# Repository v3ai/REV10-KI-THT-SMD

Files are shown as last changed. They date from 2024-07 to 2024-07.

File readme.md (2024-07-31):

These are the Kicad files for the REV-10 NSE Geiger Counter

make sure the R7 and R8 Resistors are 1% not 5%

if you wanna manufacture with jlcpcb use the included zip file. If you change anything please refer to the article below

https://jlcpcb.com/help/article/362-how-to-generate-gerber-and-drill-files-in-kicad-7

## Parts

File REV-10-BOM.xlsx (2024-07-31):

QTY | VALUE | PARTS | DESCRIPTION | MANUFACTURER PART NUMBER | VENDOR PART NUMBER | UNIT PRICE (IN 100+ BRACKET) | EXT PRICE | MEASUREMENT | SOURCE
 |  |  | RESISTORS (THT)
1 | 5.1kΩ | R1 | 1/2W resistor, metal film 700V | MF1/2CC5101F | S5.1KCACT-ND | 0.3011 | 0.3011 | 0.138" Dia x 0.354" L (3.50mm x 9.00mm) | https://www.digikey.com/en/products/detail/koa-speer-electronics-inc/MF1-2CC5101F/21680989
3 | 10kΩ | R2, R6, R9 | 1/4W resistor, carbon film | CF14JT10K0 | CF14JT10K0CT-ND | 0.0215 | 0.0645 | 0.091" Dia x 0.236" L (2.30mm x 6.00mm) | https://www.digikey.com/en/products/detail/CF14JT10K0/CF14JT10K0CT-ND/1830374
1 | 1kΩ | R3 | 1/4W resistor, carbon film | CF14JT1K00 | CF14JT1K00CT-ND | 0.0215 | 0.0215 | 0.091" Dia x 0.236" L (2.30mm x 6.00mm) | https://www.digikey.com/en/products/detail/CF14JT1K00/CF14JT1K00CT-ND/1830350
1 | 75Ω | R4 | 1/4W resistor, carbon film | CF14JT75R0 | CF14JT75R0CT-ND | 0.0215 | 0.0215 | 0.091" Dia x 0.236" L (2.30mm x 6.00mm) | https://www.digikey.com/en/products/detail/CF14JT75R0/CF14JT75R0CT-ND/1830324
1 | 6.2kΩ | R5 | 1/4W resistor, carbon film | CF14JT6K20 | CF14JT6K20CT-ND | 0.0215 | 0.0215 | 0.091" Dia x 0.236" L (2.30mm x 6.00mm) | https://www.digikey.com/en/products/detail/CF14JT6K20/CF14JT6K20CT-ND/1830369
1 | 4.7MΩ | R7 | 1/4W resistor, metal film, 1% (not 5%) | RNV14FAL4M70 | RNV14FAL4M70CT-ND | 0.063 | 0.063 | 0.094" Dia x 0.236" L (2.40mm x 6.00mm) | https://www.digikey.com/en/products/detail/stackpole-electronics-inc/RNV14FAL4M70/2665263
1 | 6.8MΩ | R8 | 0.6W resistor, carbon film, 1% (not 5%) | MBB02070C6804FCT00 | BC3869CT-ND | 0.076 | 0.076 | 0.091" Dia x 0.236" L (2.30mm x 6.00mm) | https://www.digikey.com/en/products/detail/vishay-beyschlag-draloric-bc-components/MBB02070C6804FCT00/5063554
2 | 4.7kΩ | R10, R14 | 1/4W resistor, carbon film | CF14JT4K70 | CF14JT4K70CT-ND | 0.0215 | 0.043 | 0.091" Dia x 0.236" L (2.30mm x 6.00mm) | https://www.digikey.com/en/products/detail/stackpole-electronics-inc/CF14JT4K70/1741428
1 | 10MΩ | R11 | 1/4W resistor, metal film 700V | VR25000001005JR500 | 56-VR25000001005JR500CT-ND | 0.1181 | 0.1181 | 0.098" Dia x 0.256" L (2.50mm x 6.50mm) | https://www.digikey.com/en/products/detail/vishay-beyschlag-draloric-bc-components/VR25000001005JR500/7350776
1 | 22kΩ | R12 | 1/4W resistor, carbon film | CF14JT22K0 | CF14JT22K0CT-ND | 0.0215 | 0.0215 | 0.091" Dia x 0.236" L (2.30mm x 6.00mm) | https://www.digikey.com/en/products/detail/CF14JT22K0/CF14JT22K0CT-ND/1830383
1 | 5.1MΩ | R13 | 1/4W resistor, metal film 700V | VR25000005104JA100 | BC4890CT-ND | 0.0978 | 0.0978 | 0.098" Dia x 0.256" L (2.50mm x 6.50mm) | https://www.digikey.com/en/products/detail/vishay-beyschlag-draloric-bc-components/VR25000005104JA100/7350796
1 | 20kΩ | RV1 | Potentiometer, 1/2W 1.0 Turn | 3362P-1-203LF | 3362P-203LF-ND | 0.7575 | 0.7575 | 0.275" x 0.260" Face (6.99mm x 6.60mm) | https://www.digikey.com/en/products/detail/bourns-inc/3362P-1-203LF/1088417
 |  |  | CAPACITORS (THT)
2 | 10uF | C1, C3 | MLCC in radial package with 0.1” lead spacing required | FG18X5R1E106MRT06 | 445-FG18X5R1E106MRT06CT-ND | 0.2043 | 0.4086 | 0.157" L x 0.098" W (4.00mm x 2.50mm) | https://www.digikey.com/en/products/detail/tdk-corporation/FG18X5R1E106MRT06/7384735
1 | 47pF | C2 | MLCC in radial package with 0.1” lead spacing required | SR152A470KAR | 478-3164-ND | 0.1315 | 0.1315 | 0.150" L x 0.100" W (3.81mm x 2.54mm) | https://www.digikey.com/en/products/detail/SR152A470KAR/478-3164-ND/936806
1 | 10nF = 10000pF | C4 | Ceramic in radial package 100V 0.2" lead spacing required | D103M29Z5UH6UJ5R | BC5213CT-ND | 0.062 | 0.062 | 0.295" Dia (7.50mm) | https://www.digikey.com/en/products/detail/vishay-beyschlag-draloric-bc-components/D103M29Z5UH6UJ5R/2830060
1 | 220n = 0.22uF | C5 | Ceramic in radial package with 0.2" lead spacing required | K224K20X7RF5UH5 | BC2678CT-ND | 0.124 | 0.124 | 0.197" L x 0.126" W (5.00mm x 3.20mm) | https://www.digikey.com/en/products/detail/vishay-beyschlag-draloric-bc-components/K224K20X7RF5UH5/2356767
1 | 1uF | C6 | Ceramic in radial package with 0.2” lead spacing required | FG28X7R1E105KRT00 | 445-181761-ND | 0.0899 | 0.0899 | 0.157" L x 0.098" W (4.00mm x 2.50mm) | https://www.digikey.com/en/products/detail/tdk-corporation/FG28X7R1E105KRT00/7326783
1 | 15nF | C7 | Ceramic in radial package with 0.15" lead spacing required | K153K10X7RF5UH5 | BC2671CT-ND | 0.0775 | 0.0775 | 0.142" L x 0.091" W (3.60mm x 2.30mm) | https://www.digikey.com/en/products/detail/vishay-beyschlag-draloric-bc-components/K153K10X7RF5UH5/2356760
1 | 4.7nF | C8 | Ceramic in radial package with 0.2” lead spacing required (CHV) | S472M39Z5UN63J5R | 1288PH-ND | 0.1444 | 0.1444 | 0.394" Dia (10.00mm) | https://www.digikey.com/en/products/detail/S472M39Z5UN63J5R/1288PH-ND/2356824
 |  |  | INDUCTORS
1 | 1mH | L1 | Inductor, radial package | RLB0914-102KL | RLB0914-102KL-ND | 0.26875 | 0.26875 | 0.343" Dia (8.70mm) | https://www.digikey.com/en/products/detail/bourns-inc/RLB0914-102KL/2352773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
 |  |  | DIODES
1 | LED | D1 | Blue LED 3mm,3 3.3V | WP710A10QBC/D | 754-1596-ND | 0.151 | 0.151 | 2.90mm Dia | https://www.digikey.com/en/products/detail/WP710A10QBC%2FD/754-1596-ND/2769812
1 | BA159 | D2 | Fast switching diode, DO-41 package required | BA159-E3/54 | BA159-E3/54GICT-ND | 0.1171 | 0.1171 | DO-204AL (DO-41) | https://www.digikey.com/en/products/detail/BA159-E3%2F54/BA159-E3%2F54GICT-ND/3711780
 |  |  | IC
1 | NJM78M05FA | U1 | Linear Voltage Regulator 5V at 500mA | NJM78M05FA | 2129-NJM78M05FA-ND | 0.7562 | 0.7562 | TO-220F | https://www.digikey.com/en/products/detail/nisshinbo-micro-devices-inc/NJM78M05FA/805792
1 | LMC555 | U2 | LMC555 CMOS-based 555 timer | LMC555CN/NOPB | LMC555CN/NOPB-ND | 1.10575 | 1.10575 | 8-DIP (0.300", 7.62mm) | https://www.digikey.com/en/products/detail/texas-instruments/LMC555CN-NOPB/32623
2 | STQ | U3, U4 | N Channel MOSFET 600V 400MA TO92-3 | STQ1HNK60R-AP | 497-15648-1-ND | 0.3879 | 0.7758 | TO-92-3 | https://www.digikey.com/en/products/detail/stmicroelectronics/STQ1HNK60R-AP/3945986
1 | TL5001 | U5 | Power converter control chip | TL5001AIP | 296-10203-5-ND | 2.9365 | 2.9365 | 8-DIP (0.300", 7.62mm) | https://www.digikey.com/en/products/detail/texas-instruments/TL5001AIP/380448
1 | 2N3904 | Q1 | NPN Transistor, TO-92 package | 2N3904BU | 2N3904FS-ND | 0.1169 | 0.1169 | TO-226-3, TO-92-3 (TO-226AA) | https://www.digikey.com/en/products/detail/2N3904BU/2N3904FS-ND/1413
 |  |  | MISC
1 | SBM-20 |  | Geiger Tube | SBM-20 | SBM-20 | 13 | 13 | Max Len = 108 / 101 Eff Length =91.0 / 83.5 (mm) | https://www.sovtube.com/x-ray-and-geiger-tubes/341-sbm-20.html
2 | DIP8 |  | DIP SOCKET 8 pos | ED08DT | ED3044-5-ND | 0.16283 | 0.32566 | DIP, 0.3" (7.62mm) Row Spacing | https://www.digikey.com/en/products/detail/ED08DT/ED3044-5-ND/4147594
2 | CLIPS |  | Fuse clips to hold SBM-20 | 3530 | 36-3530-ND | 0.2635 | 0.527 | Fuse Size 0.25" Dia (6.35mm) | https://www.digikey.com/en/products/detail/keystone-electronics/3530/316021
1 | BOARD |  | MIT-NSE Geiger Counter Board | REV9 | REV9 | 1.1677 | 1.1677 | <BOARD DIMENSIONS> | https://jlcpcb.com/
1 | CASE |  | Serpac enclosure, black, clear top | 052C,BK | 052C,BK | 7.29 | 7.29 | 5.62 x 3.25 x 1.4 in | https://www.serpac.com/x5x-enclosure.html#93=250&162=31&167=60&170=219&177=95&182=253
1 | SWITCH |  | SPST Circular Switch | SW-R2-1A-F-1-5 | 2057-SW-R2-1A-F-1-5-ND | 0.4232 | 0.4232 | Circular - 20.00mm Dia | https://www.digikey.com/en/products/detail/adam-tech/SW-R2-1A-F-1-5/15284451
1 | HOLD |  | 9V Battery holder | BA9VPC | BA9VPC-ND | 1.7901 | 1.7901 | Height Above Board 0.843" (21.41mm) | https://www.digikey.com/en/products/detail/mpd-memory-protection-devices/BA9VPC/2439228
1 | BATT |  | Energizer Industrial 9V | EN22 | EN22 | 1.431 | 1.431 | 49x46.5mm | https://a.co/d/gEASXDG
2 | SPADE |  | Spade Connectors | 197084013 | WM14275CT-ND | 0.0836 | 0.1672 | Length 0.510" (12.95mm), Width 0.187" (4.75mm) | https://www.digikey.com/en/products/detail/molex/0197084013/3183362
4 | SCREW |  | #4-40x3/16” pan head thread-cutting screw | 90087A105 | 90087A105 | 0.1018 | 0.4072 | #4-40x3/16” | https://www.mcmaster.com/90087A105/
2 | CONN |  | Female To Female spade connection wires (4.8mm) | N/A | N/A | 0.467 | 0.934 | 4.8mm spade, 11.82" Length | https://a.co/d/c38sBzh
1 | AUDIO | J2 | Audio Connection Jack (female) 3.5mm | 54-00298 | 839-54-00298CT-ND | 0.8888 | 0.8888 | 3.50mm (0.141", 1/8", Mini Plug) - Headphone | https://www.digikey.com/en/products/detail/tensility-international-corp/54-00298/16579528
 |  |  | OPTIONAL
1 | ESP32 |  | ESP32-C3-DevKitC-02 | ESP32-C3-DevKitC-02 | 356-ESP32C3DEVKITC02 | 8 | 8 |  | https://www.mouser.com/ProductDetail/Espressif-Systems/ESP32-C3-DevKitC-02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
2 | HEADER |  | 15 POS Female pinheader | PPTC151LFBN-RC | S7013-ND | 0.75075 | 1.5015 | Pitch - Mating 0.100" (2.54mm) | https://www.digikey.com/en/products/detail/sullins-connector-solutions/PPTC151LFBN-RC/810153
1 | PWR | J1 | 9V Connection Power Jack (Female) 2.1X5.5mm | EJ508A | EJ508A-ND | 1.0443 | 1.0443 | 2.1x5.5mm | https://www.digikey.com/en/products/detail/mpd-memory-protection-devices/EJ508A/2439547
1 | M4011 |  | Alternate usable geiger tube | M4011
 |  |  | PACKAGING
1 | BOX |  | 8 x 8 x 2-Inch Literature Mailers |  |  | 0.8014 | 0.8014 | 8" x 8" x 2" | https://a.co/d/04CDcmVn
7 | PINK BAG |  | Pink Anti-Static Seal Top Bag |  |  | 0.083 | 0.581 | 2.5" x 3" | https://a.co/d/08yDM0mG
27 | BAG |  | Zipper Lock Reclosable Clear Disposable Plastic Bags |  |  | 0.01299 | 0.35073 | 2" X 3" - 2 MIL | https://a.co/d/06HEltN5
1 | BUBBLE |  | Anti Static Bubble coushining for SBM-20 and Board |  |  | 0.17 | 0.17 | 1ft | https://a.co/d/0cyxP9Bv
26 | LABEL |  | Premium Label Supply White Sticker Square Labels – 1.5” x 1.5" |  |  | 0.02 | 0.52 | 1.5"x1.5" | https://a.co/d/9N4nW4M
1 | BIG BAG |  | GPI - 100 Count 8" X 8" Zip Bags, Heavy-Duty 4 Mil Thick, |  |  | 0.13 | 0.13 | 8" x 8" | https://a.co/d/488i0Rc
1 | INSERT |  |  |  |  |  | 0
12 | INSTRUCTIONS |  | 12 pages color |  |  | 0.15 | 1.8
 |  |  | ALTERNATE SMD R and C
 |  |  | RESISTORS (SMD)
1 | 5.1kΩ | R1 | 5.1 kOhms ±1% 0.25W, 1/4W Chip Resistor 1206 (3216 Metric) Automotive AEC-Q200 Thick Film (200V) | CRCW12065K10FKEA | 541-5.10KFCT-ND | 0.0316 |  | 1206 (3216 Metric) | https://www.digikey.com/en/products/detail/vishay-dale/CRCW12065K10FKEA/1176724
3 | 10kΩ | R2, R6, R9 | 10 kOhms ±1% 0.25W, 1/4W Chip Resistor 1206 (3216 Metric) Automotive AEC-Q200 Thick Film | RMCF1206FT10K0 | RMCF1206FT10K0CT-ND | 0.013 |  | 1206 (3216 Metric) | https://www.digikey.com/en/products/detail/stackpole-electronics-inc/RMCF1206FT10K0/1759669
1 | 1kΩ | R3 | RES 1K OHM 5% 1/4W 1206 | RMCF1206JT1K00 | RMCF1206JT1K00CT-ND | 0.01 |  | 1206 (3216 Metric) | https://www.digikey.com/en/products/detail/stackpole-electronics-inc/rmcf1206jt1k00/1757526
1 | 75Ω | R4 | RES 75 OHM 5% 1/4W 1206 | RMCF1206JT75R0 | RMCF1206JT75R0CT-ND | 0.01 |  | 1206 (3216 Metric) | https://www.digikey.com/en/products/detail/stackpole-electronics-inc/rmcf1206jt75r0/1753880
1 | 6.2k | R5 | 6.2 kOhms ±1% 0.25W, 1/4W Chip Resistor 1206 (3216 Metric) Automotive AEC-Q200 Thick Film | RMCF1206FT6K20 | RMCF1206FT6K20CT-ND | 0.013 |  | 1206 (3216 Metric) | https://www.digikey.com/en/products/detail/stackpole-electronics-inc/RMCF1206FT6K20/1759189
1 | 4.7M | R7 | 4.7 MOhms ±1% 0.25W, 1/4W Chip Resistor 1206 (3216 Metric) Automotive AEC-Q200 Thick Film | RMCF1206FT4M70 | RMCF1206FT4M70CT-ND | 0.017 |  | 1206 (3216 Metric) | https://www.digikey.com/en/products/detail/stackpole-electronics-inc/RMCF1206FT4M70/1759348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
1 | 6.8M | R8 | RES 6.8M OHM 1% 1/4W 1206 | RMCF1206FT6M80 | RMCF1206FT6M80CT-ND | 0.017 |  | 1206 (3216 Metric) | https://www.digikey.com/en/products/detail/stackpole-electronics-inc/RMCF1206FT6M80/1754115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
2 | 4.7k | R10, R14 | RES 4.7K OHM 5% 1/4W 1206 | RMCF1206JT4K70 | RMCF1206JT4K70CT-ND | 0.01 |  | 1206 (3216 Metric) | https://www.digikey.com/en/products/detail/stackpole-electronics-inc/rmcf1206jt4k70/1753837
1 | 10M | R11 | 10 MOhms ±5% 0.25W, 1/4W Chip Resistor 1206 (3216 Metric) Automotive AEC-Q200 Thick Film | RMCF1206JT10M0 | RMCF1206JT10M0CT-ND | 0.011 |  | 1206 (3216 Metric) | https://www.digikey.com/en/products/detail/stackpole-electronics-inc/RMCF1206JT10M0/1757578
1 | 22k | R12 | 22 kOhms ±5% 0.25W, 1/4W Chip Resistor 1206 (3216 Metric) Automotive AEC-Q200 Thick Film | RMCF1206JT22K0 | RMCF1206JT22K0CT-ND | 0.011 |  | 1206 (3216 Metric) | https://www.digikey.com/en/products/detail/stackpole-electronics-inc/RMCF1206JT22K0/1757375
1 | 5.1M,0.7kV | R13 | 5.1 MOhms ±5% 0.25W, 1/4W Chip Resistor 1206 (3216 Metric) Automotive AEC-Q200 Thick Film | RMCF1206JG5M10 | 738-RMCF1206JG5M10CT-ND | 0.0104 |  | 1206 (3216 Metric) | https://www.digikey.com/en/products/detail/stackpole-electronics-inc/RMCF1206JG5M10/1753851
1 | 20k | RV1 | 20 kOhms 0.5W, 1/2W PC Pins Through Hole Trimmer Potentiometer Cermet 1.0 Turn Top Adjustment | 3362P-1-203LF | 3362P-203LF-ND | 0.7575 |  | 0.275" x 0.260" Face (6.99mm x 6.60mm) | https://www.digikey.com/en/products/detail/bourns-inc/3362P-1-203LF/1088417
 |  |  | CAPACITORS (SMD)
2 | 10uF | C1, C3 | 10 µF ±20% 25V Ceramic Capacitor X5R 1206 (3216 Metric) | CL31A106MAHNNNE | 1276-1181-1-ND | 0.059 |  | 1206 (3216 Metric) | https://www.digikey.com/en/products/detail/samsung-electro-mechanics/CL31A106MAHNNNE/3886839
1 | 47pF | C2 | CAP CER 47PF 200V NP0 1206 | 12062A470JAT2A | 478-12810-1-ND | 0.119 |  | 1206 (3216 Metric) | https://www.digikey.com/en/products/detail/kyocera-avx/12062A470JAT2A/1604098
1 | 10nF = 10000pF | C4 | CAP CER 0.015UF 50V X7R 1206 | C1206C153K5RAC7800 | 399-C1206C153K5RAC7800CT-ND | 0.119 |  | 1206 (3216 Metric) | https://www.digikey.com/en/products/detail/kemet/C1206C153J5RAC7800/2215279
1 | 220n = 0.22uF | C5 | 0.22 µF ±5% 25V Ceramic Capacitor X7R 1206 (3216 Metric) | 12063C224JAT2A | 478-12815-1-ND | 0.138 |  | 1206 (3216 Metric) | https://www.digikey.com/en/products/detail/kyocera-avx/12063C224JAT2A/1604316
1 | 1uF | C6 | 1 µF ±10% 100V Ceramic Capacitor X7R 1206 (3216 Metric) | CL31B105KCHNFNE | 1276-3094-1-ND | 0.086 |  | 1206 (3216 Metric) | https://www.digikey.com/en/products/detail/samsung-electro-mechanics/CL31B105KCHNFNE/3888752
1 | 15n | C7 | CAP CER 0.015UF 50V X7R 1206 | C1206C153K5RAC7800 | 399-C1206C153K5RAC7800CT-ND | 0.119 |  | 1206 (3216 Metric) | https://www.digikey.com/en/products/detail/kemet/C1206C153J5RAC7800/2215279
1 | 4.7nF, 630V | C8 | CAP CER 0.047UF 630V X7R 1210 (works great but was not the one specified, 4.7nf vs 0.047uf) | C1210C473KBRACAUTO | 399-C1210C473KBRACAUTOCT-ND | 0.183 |  | 1210 (3225 Metric) | https://www.digikey.com/en/products/detail/kemet/C1210C473KBRACAUTO/10482991

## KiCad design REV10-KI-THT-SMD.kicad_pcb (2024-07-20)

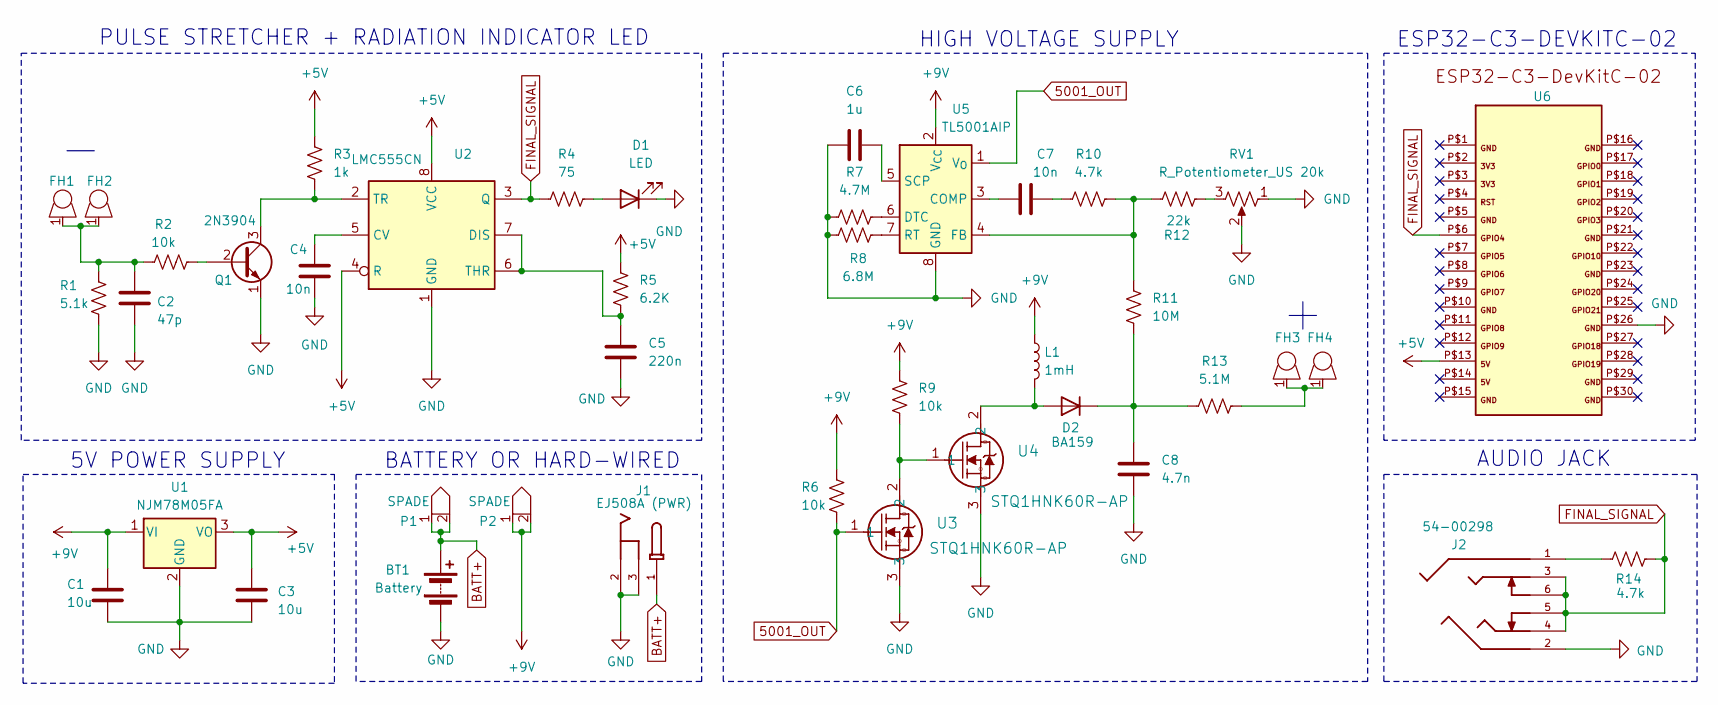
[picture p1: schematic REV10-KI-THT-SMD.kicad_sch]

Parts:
BT1: Battery; BatteryHolder_MPD_BA9VPC_1xPP3
C1, C3: 10u; C_THT_SMD
C2: 47p; C_THT_SMD
C4, C7: 10n; C_THT_SMD
C5: 220n; C_THT_SMD
C6: 1u; C_THT_SMD
C8: 4.7n; CHV
D1: LED; LED_D3.0mm
D2: BA159; D_DO-41_SOD81_P7.62mm_Horizontal
FH1, FH2, FH3, FH4: 36-3530-ND
J1: EJ508A (PWR); MPD_EJ508A; PARTREV J
J2: 54-00298; PARTREV A
L1: 1mH; L_Radial_D8.7mm_P5.00mm_Fastron_07HCP
P1, P2: SPADE; 0197084013
Q1: 2N3904; TO-92_Inline_Wide
R1: 5.1k; R_BIG
R2, R6, R9: 10k; R_SMALL
R3: 1k; R_SMALL
R4: 75; R_SMALL
R5: 6.2K; R_SMALL
R7: 4.7M; R_SMALL
R8: 6.8M; R_SMALL
R10, R14: 4.7k; R_SMALL
R11: 10M; R_SMALL
R12: 22k; R_SMALL
R13: 5.1M; R_SMALL
RV1: R_Potentiometer_US 20k; POT_3362P
U1: NJM78M05FA; TO-220-3_Vertical
U2: LMC555CN; DIP-8_W7.62mm
U3, U4: STQ1HNK60R-AP; TO-92_Inline_Wide
U5: TL5001AIP; DIP-8_W7.62mm
U6: ESP32-C3-DEVKITC-02HOLES; ESP32-C3-DevKitC-02

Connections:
5001_OUT: R6.2, U3.1, U5.1 (V_{O})
+5V: C3.1, R3.1, R5.1, U1.3 (VO), U2.4 (R), U2.8 (VCC), U6.P$13
+9V: C1.1, L1.1, P2.1, P2.2, R6.1, R9.1, U1.1 (VI), U5.2 (V_{CC})
BATT+: BT1.1 (+), J1.1, P1.1, P1.2
FINAL_SIGNAL: J2.3, J2.4, J2.5, J2.6, R4.1, R14.2, U2.3 (Q), U6.P$6
GND: BT1.2 (-), C1.2, C2.2, C3.2, C4.1, C5.2, C6.1, C8.2, D1.1 (K), J1.2, J1.3, J2.2, Q1.1 (E), R1.2, R7.1, R8.1, RV1.1, RV1.2, U1.2 (GND), U2.1 (GND), U3.3, U4.3, U5.8 (GND), U6.P$26
unnamed: C2.1, FH1.1, FH2.1, R1.1, R2.1
unnamed: C7.2, R10.1
unnamed: D1.2 (A), R4.2
unnamed: D2.2 (A), L1.2, U4.2
unnamed: C8.1, D2.1 (K), R11.2, R13.1
unnamed: FH3.1, FH4.1, R13.2
unnamed: J2.1, R14.1
unnamed: Q1.2 (B), R2.2
unnamed: Q1.3 (C), R3.2, U2.2 (TR)
unnamed: R9.2, U3.2, U4.1
unnamed: R12.2, RV1.3
unnamed: C4.2, U2.5 (CV)
unnamed: C5.1, R5.2, U2.6 (THR), U2.7 (DIS)
unnamed: C7.1, U5.3 (COMP)
unnamed: R7.2, U5.6 (DTC)
unnamed: R10.2, R11.1, R12.1, U5.4 (FB)
unnamed: R8.2, U5.7 (RT)
unnamed: C6.2, U5.5 (SCP)

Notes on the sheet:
HIGH VOLTAGE SUPPLY
AUDIO JACK
BATTERY OR HARD-WIRED
ESP32-C3-DEVKITC-02
PULSE STRETCHER + RADIATION INDICATOR LED
5V POWER SUPPLY

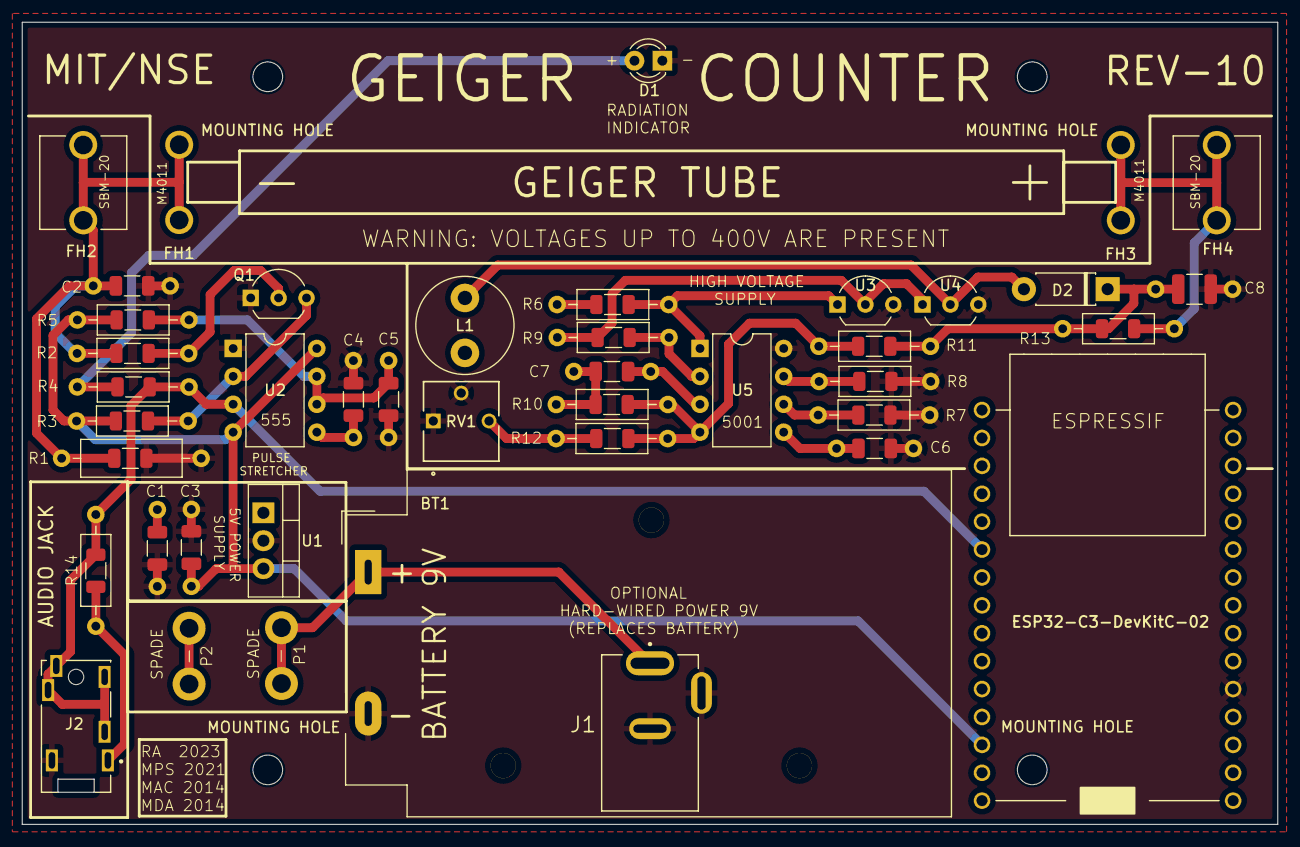
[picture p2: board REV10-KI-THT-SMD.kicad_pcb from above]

Board: 2 copper layers, 114.3 x 73.0 mm, 46 parts (0 on the bottom side), 24 nets.

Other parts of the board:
MOUNTING HOLE: MountingHole_2.7mm
MOUNTING HOLE#2, MOUNTING HOLE#3, MOUNTING HOLE#4: MountingHole_2.7mm

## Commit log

2024-07-09 already some changes june 9 first comm
    [REV10-KI-THT-SMD.kicad_pcb, REV10-KI-THT-SMD.kicad_sch]
2024-07-12 first dual
    [REV10-KI-THT-SMD.kicad_pcb, REV10-KI-THT-SMD.kicad_sch]
2024-07-20 added holes for m4011, removed rev 9 backups
    [REV10-KI-THT-SMD.kicad_pcb, REV10-KI-THT-SMD.kicad_sch]
2024-07-20 added readme
    [REV10-KI-THT-SMD.kicad_pcb]
2024-07-20 small updates, name, moving j1 a small bit
    [REV10-KI-THT-SMD.kicad_pcb]
2024-07-24 changed 10nf to 15nf, realized the old design had that cap as 15, trying to stay true
    [REV10-KI-THT-SMD.kicad_sch]
2024-07-31 july 31st
    [REV-10-BOM.xlsx]
